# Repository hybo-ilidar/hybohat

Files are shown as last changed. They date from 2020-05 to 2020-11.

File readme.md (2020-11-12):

# Hybohat Development Board 

## Update R3

Correction was made for Arduino Nano module.
ESP32 module was adjusted for use with male pin header modules.

## Introduction

The Hybohat module was designed as a simple, passive way to interconnect
the User I/O connector of the iLidar to a variety of common development
boards.  These are:

* STM32F4 Discovery
* Arduino Uno & Leonardo
* STM32F429ZI Nucleo
* ESP32
* Raspberry Pi & Pi Zero
* Arduino Nano (and STM32F103 Nano form-factor)

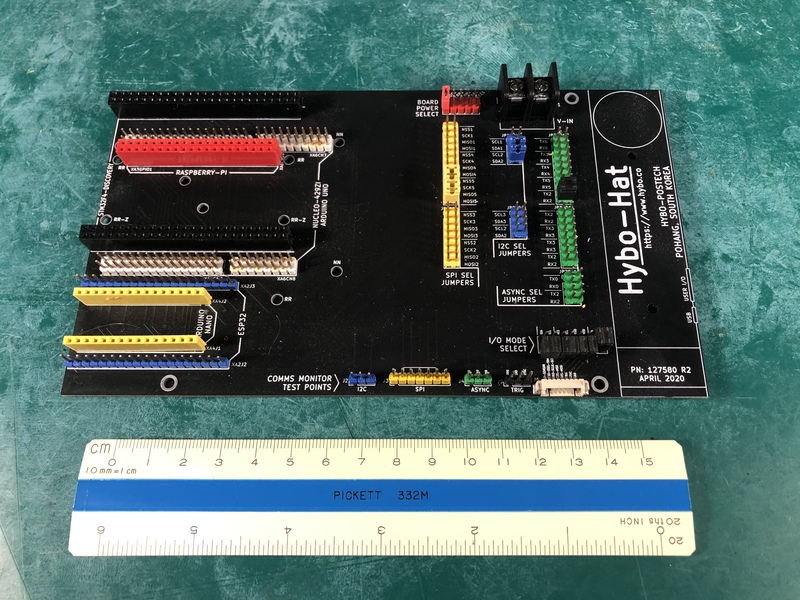
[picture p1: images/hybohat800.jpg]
Hybohat Assembly


## Concept

The board can be envisioned as a large cross-bar switch with each
dev board's I/O ports conected to a bus.  In case a development board
has multiple ports of the same time, the desired port is selected with 
jumpers in the three vertical columns labeled 

* `SPI SEL JUMPERS` (JP4NN1, JP4DD1)
* `I2C SEL JUMPERS` (JP2NN1, JP2DD1)
* `ASYNC SEL JUMPERS` (JP3NN1, JP3DD1, JP2EE1)

One end of this bus is connected to iLidar's User I/O
connector by the jumper block labeled: `I/O MODE SELECT (JP6)`
Note that only one mode can be operational at a time.

The other end of the bus is terminated in four connectors which can be
used to probe and monitor the I/O:

* `I2C` (J2)
* `SPI` (J3)
* `ASYNC` (J4)
* `TRIG` (J5)

## Development Boards

IMPORTANT: ONLY ONE DEVELOPMENT BOARD MAY BE CONNECTED AT ONE TIME

* Module A2, ESP32
  - XA2J2
  - XA2J3

* Module A3, Raspberry Pi & Pi Zero
  - XA3GPIO1

* Module A4, Arduino Nano
  - XA4J1 
  - XA4J2 

* Module A5, STM32F4 Discovery 
  - XA5P1
  - XA5P2

* Module A6, STM32F429ZI Nucleo Arduino Uno & Leonardo
  - XA6CN7
  - XA6CN8
  - XA6CN9
  - XA6CN10

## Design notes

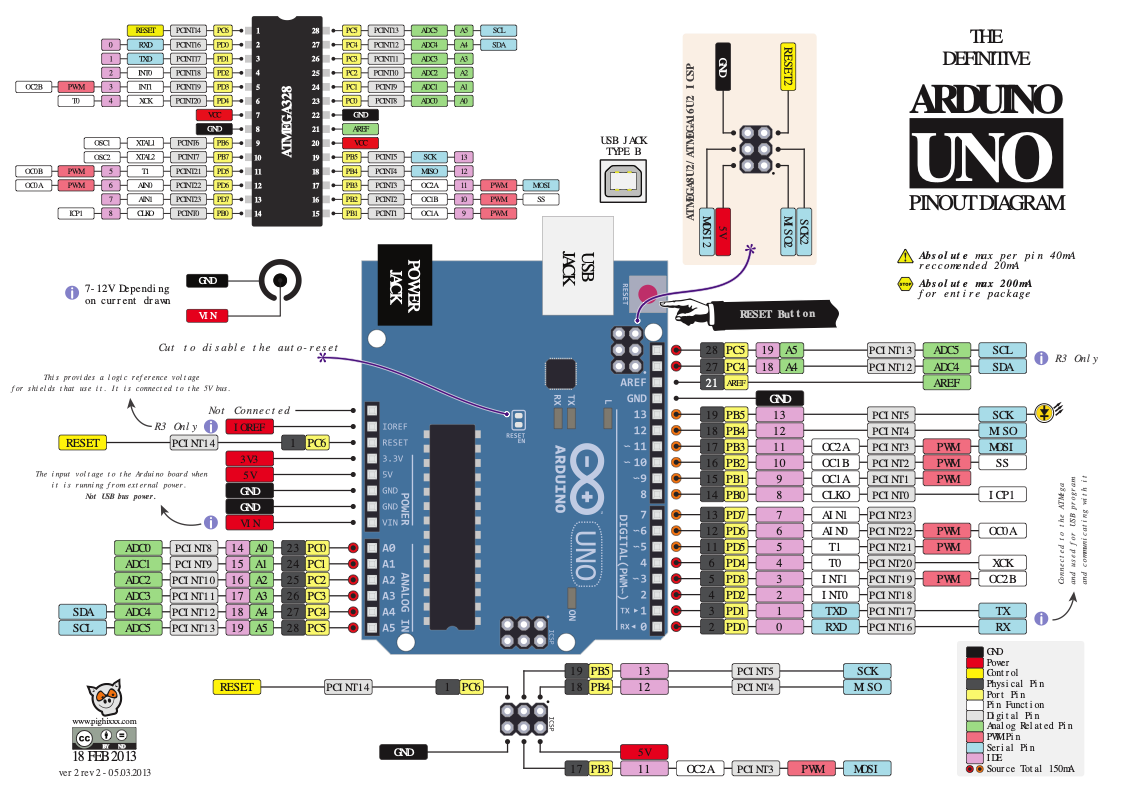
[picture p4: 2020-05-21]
datasheets/modules/pinout-arduino-uno.png

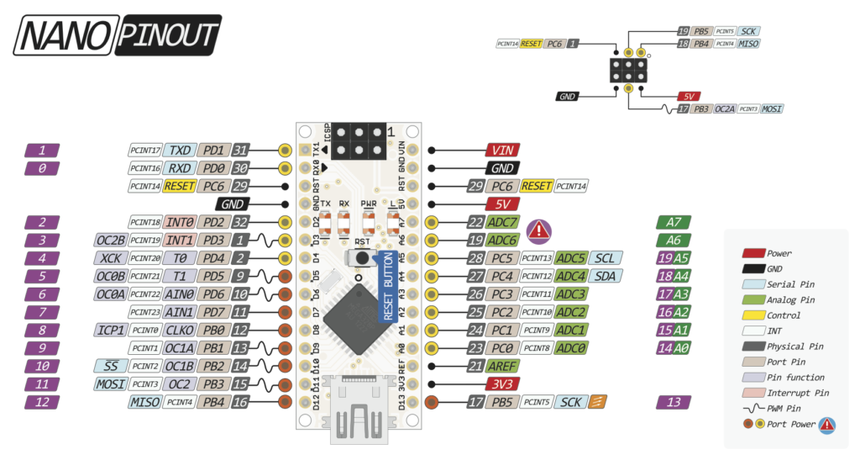
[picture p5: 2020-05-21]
datasheets/modules/pinout-arduino-nano.png

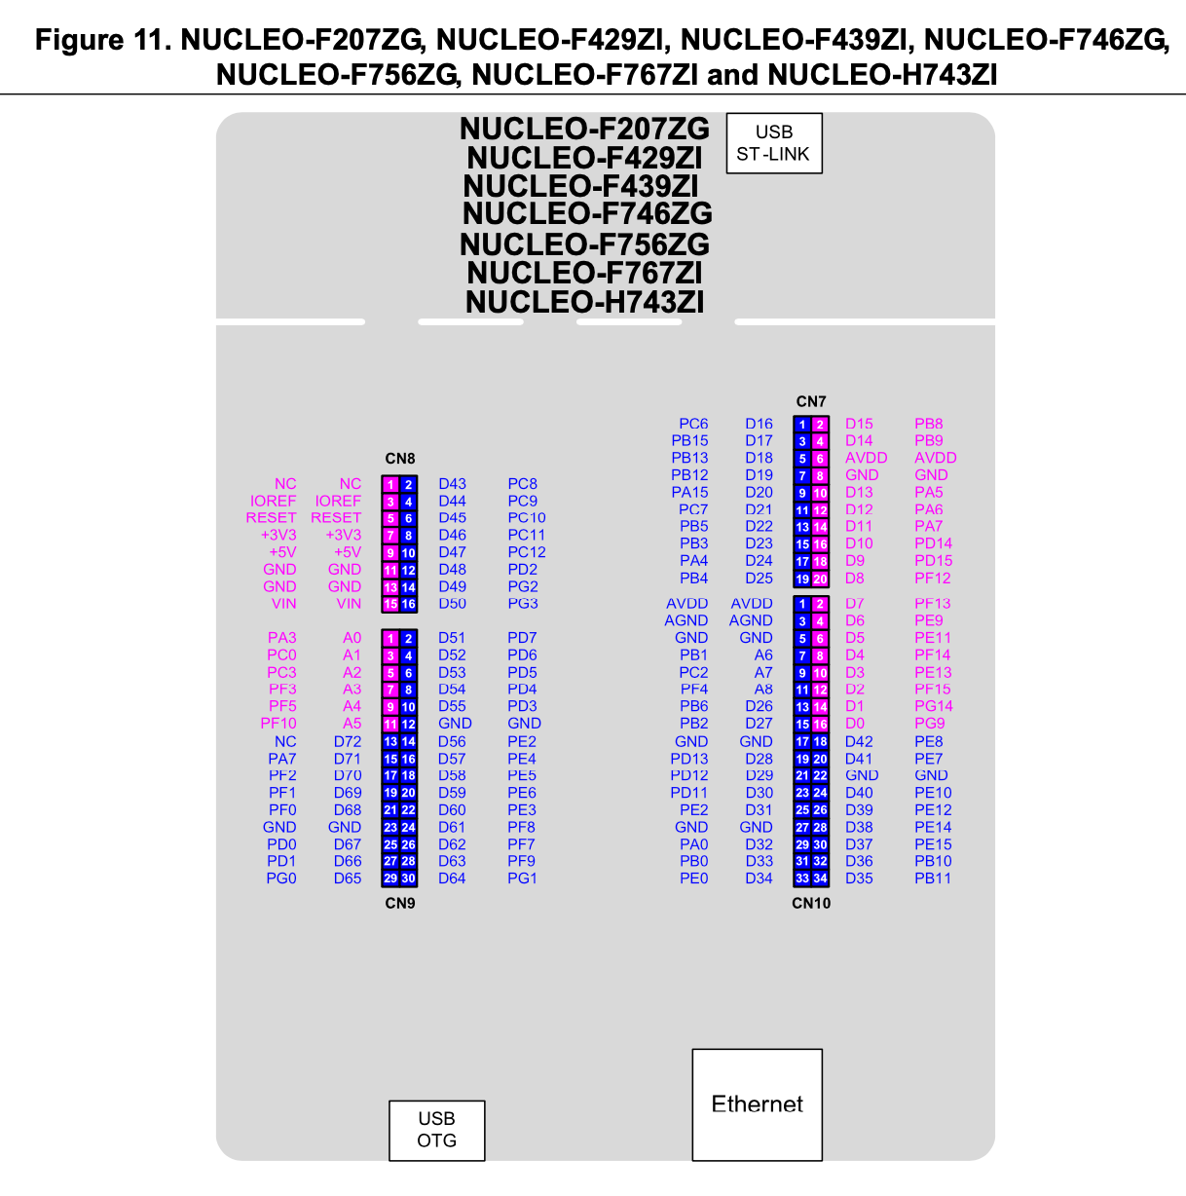
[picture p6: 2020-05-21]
datasheets/modules/pinout-nucleo-429zi.png

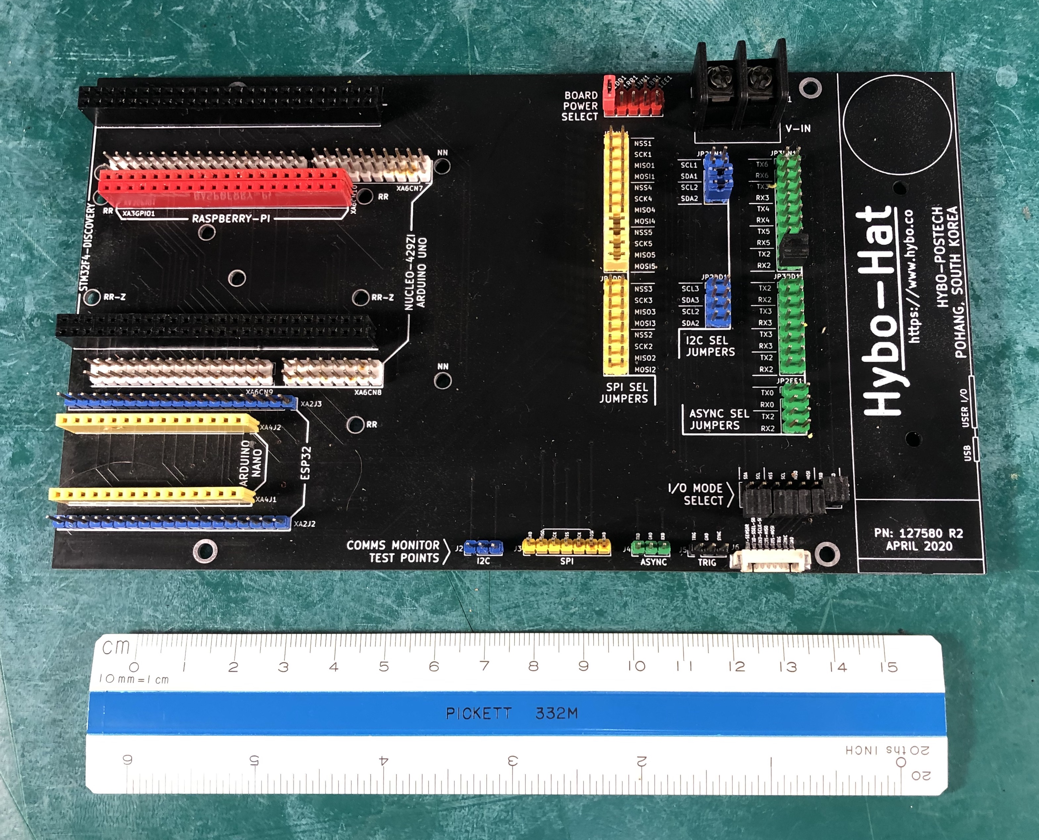
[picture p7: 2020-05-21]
images/hybohat-assy-top.jpg

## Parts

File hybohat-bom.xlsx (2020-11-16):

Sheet: BOM
HYBOHAT ASSEMBLY
P/N 127580
2020-11-11
FN | Ref | ALL Qty | EE Qty | RR Qty | BB Qty | DD Qty | NN Qty | Comm Code | Manufacturer | PartNumber | Value | Cmp name | Module
1 | A1, | 1 | 1 | 1 | 1 | 1 | 1 | ASY | Hybo | 127290 | ASSY_SENSOR_LIDAR | ASSY_SENSOR_LIDAR |  |  |  |  | iLidar Sensor
~~2~~ | ~~A2~~ |  | ~~1~~ |  |  |  |  | ASY |  |  |  |  |  |  |  |  | ESP32
~~3~~ | ~~A3~~ |  |  | ~~1~~ |  |  |  | ASY |  |  |  |  |  |  |  |  | Raspberry Pi & Pi Zero
~~4~~ | ~~A4~~ |  |  |  | ~~1~~ |  |  | ASY |  |  |  |  |  |  |  |  | Arduino Nano (and STM32F103 Nano form-factor)
~~5~~ | ~~A5~~ |  |  |  |  | ~~1~~ |  | ASY |  |  |  |  |  |  |  |  | STM32F4 Discovery
~~6~~ | ~~A6~~ |  |  |  |  |  | ~~1~~ | ASY |  |  |  |  |  |  |  |  | STM32F429ZI Nucleo, Arduino Uno & Leonardo
7 | J1, | 1 | 1 | 1 | 1 | 1 | 1 | CON | Molex | 387007502 | DC-PWR-IN | Screw_Terminal_01x02 |  |  |  |  | Connector, Barrier Strip, #6032, 0.325 in pitch, 2 pos'n
8 | J6, | 1 | 1 | 1 | 1 | 1 | 1 | CON | Molex | 532610871 | CONN_1x8 | CONN_1x8 |  | M1x08 |  |  | Connector, Plug, Wafer Pico-Blade, SMD R/A,1.25 mm pitch, 8-pos'n
~~9~~ | J2 | ~~1~~ | ~~1~~ | ~~1~~ | ~~1~~ | ~~1~~ | ~~1~~ | CON |  |  | IO_JACK_M03 | IO_JACK_M03 | I2C | M1x03 | M1 | 3 | Header, Pin, Vertical, 0.1 in. pitch, 0.12/0.23 in head/tail, 1x3 pos'n
~~10~~ | J4 | ~~1~~ | ~~1~~ | ~~1~~ | ~~1~~ | ~~1~~ | ~~1~~ | CON |  |  | IO_JACK_M03 | IO_JACK_M03 | ASYNC | M1x03 | M1 | 3 | Header, Pin, Vertical, 0.1 in. pitch, 0.12/0.23 in head/tail, 1x3 pos'n
~~11~~ | J5 | ~~1~~ | ~~1~~ | ~~1~~ | ~~1~~ | ~~1~~ | ~~1~~ | CON |  |  | IO_JACK_M03 | IO_JACK_M03 | TRIG | M1x03 | M1 | 3 | Header, Pin, Vertical, 0.1 in. pitch, 0.12/0.23 in head/tail, 1x3 pos'n
~~12~~ | J3, | ~~1~~ | ~~1~~ | ~~1~~ | ~~1~~ | ~~1~~ | ~~1~~ | CON |  |  | IO_JACK_M07 | IO_JACK_M07 | SPI | M1x07 | M1 | 7 | Header, Pin, Vertical, 0.1 in. pitch, 0.12/0.23 in head/tail, 1x7 pos'n
~~13~~ | JP1 | ~~1~~ | 1 | 1 | 1 | 1 | 1 | CON |  |  | PWR-SEL | IO_JACK_M2x01B | POWER | M2x10 | M2 | 10 | Header, Pin, Vertical, 0.1 in. pitch, 0.12/0.23 in head/tail, 2x10 pos'n
~~14~~ | JP6 | ~~1~~ | 1 | 1 | 1 | 1 | 1 | CON |  |  | IO_JACK_M2x08B | IO_JACK_M2x08B_SENSOR | MODE | M2x08 | M2 | 8 | Header, Pin, Vertical, 0.1 in. pitch, 0.12/0.23 in head/tail, 2x8 pos'n
15 | LK1-LK17 | 17 | 17 | 17 | 17 | 17 | 17 | CON | Sullins | QPC02SXGN-RC |  |  | POWER | LKx01 |  |  | Connector, Shorting Jumper, 0.1 in. pitch
20 |  | 1 | 1 | 1 | 1 | 1 | 1 | PCB | Hybo | 127581 |  |  |  |  |  |  | Printed circuit board, Hybohat
~~21~~ | XA2J2, XA2J3 | ~~2~~ | ~~2~~ |  |  |  |  | CON | Sullins | PPPC201LFBN-RC | EE_F1x19_J2 | IO_JACK_F19 | EE | F1x19 | F1 | 38 | Header, Socket, Vertical, 0.1 in. pitch, 0.12/0.23 in head/tail, 1x19 pos'n
~~22~~ | JP2EE1, | ~~1~~ | ~~1~~ |  |  |  |  | CON |  |  | EE_ASYNC_SEL | IO_JACK_M2x04B | EE | M2x04 | M2 | 4 | Header, Pin, Vertical, 0.1 in. pitch, 0.12/0.23 in head/tail, 2x4 pos'n
23 | XA3GPIO1, | 1 |  | 1 |  |  |  | CON | Sullins | PPPC202LFBN-RC | RR_F2x20_GPIO | IO_JACK_F2x20B | RR | F2x20 | F2 | 20 | Header, Socket, Vertical, 0.1 in. pitch, 0.12/0.23 in head/tail, 2x20 pos'n
24 | XA4J1, XA4J2 | 2 |  |  | 2 |  |  | CON | Sullins | PPPC151LFBN-RC | BB_F1x15_J1 | IO_JACK_F15 | BB | F1x15 | F1 | 30 | Header, Socket, Vertical, 0.1 in. pitch, 0.12/0.23 in head/tail, 2x15 pos'n
25 | XA5P1, XA5P2 | 2 |  |  |  | 2 |  | CON | Sullins | PPPC252LFBN-RC | DD_F2x25_P1 | IO_JACK_F2x25 | DD | F2x25 | F2 | 50 | Header, Socket, Vertical, 0.1 in. pitch, 0.12/0.23 in head/tail, 2x25 pos'n
~~26~~ | JP2DD1, | ~~1~~ |  |  |  | ~~1~~ |  | CON |  |  | DD_I2C_SEL | IO_JACK_M2x04B | DD | M2x04 | M2 | 4 | Header, Pin, Vertical, 0.1 in. pitch, 0.12/0.23 in head/tail, 2x4 pos'n
~~27~~ | JP3DD1, | ~~1~~ |  |  |  | ~~1~~ |  | CON |  |  | DD_ASYNC_SEL | IO_JACK_M2x08B | DD | M2x08 | M2 | 8 | Header, Pin, Vertical, 0.1 in. pitch, 0.12/0.23 in head/tail, 2x8 pos'n
~~28~~ | JP4DD1, | ~~1~~ |  |  |  | ~~1~~ |  | CON |  |  | DD_SPI_SEL | IO_JACK_M2x08B | DD | M2x08 | M2 | 8 | Header, Pin, Vertical, 0.1 in. pitch, 0.12/0.23 in head/tail, 2x8 pos'n
~~29~~ | XA6CN7, | ~~1~~ |  |  |  |  | ~~1~~ | CON |  |  | NN_M2x10_CN7 | IO_JACK_M2x10B_NN429ZI | NN | M2x10 | M2 | 10 | Header, Pin, Vertical, 0.1 in. pitch, 0.12/0.23 in head/tail, 2x10 pos'n
~~30~~ | XA6CN8, | ~~1~~ |  |  |  |  | ~~1~~ | CON |  |  | NN_M2x8_CN8 | IO_JACK_M2x08B_NN429ZI | NN | M2x08 | M2 | 8 | Header, Pin, Vertical, 0.1 in. pitch, 0.12/0.23 in head/tail, 2x8 pos'n
~~31~~ | XA6CN9, | ~~1~~ |  |  |  |  | ~~1~~ | CON |  |  | NN_M2x15_CN9 | IO_JACK_M2x15B_NN429ZI | NN | M2x15 | M2 | 15 | Header, Pin, Vertical, 0.1 in. pitch, 0.12/0.23 in head/tail, 2x15 pos'n
~~32~~ | XA6CN10, | ~~1~~ |  |  |  |  | ~~1~~ | CON |  |  | NN_M2x17_CN10 | IO_JACK_M2x17B_NN429ZI | NN | M2x17 | M2 | 17 | Header, Pin, Vertical, 0.1 in. pitch, 0.12/0.23 in head/tail, 2x17 pos'n
~~33~~ | JP2NN1, | ~~1~~ |  |  |  |  | ~~1~~ | CON |  |  | NN_I2C_SEL | IO_JACK_M2x04B | NN | M2x04 | M2 | 4 | Header, Pin, Vertical, 0.1 in. pitch, 0.12/0.23 in head/tail, 2x17 pos'n
~~34~~ | JP3NN1, | ~~1~~ |  |  |  |  | ~~1~~ | CON |  |  | NN_ASYNC_SEL | IO_JACK_M2x10B | NN | M2x10 | M2 | 10 | Header, Pin, Vertical, 0.1 in. pitch, 0.12/0.23 in head/tail, 2x10 pos'n
~~35~~ | JP4NN1, | ~~1~~ |  |  |  |  | ~~1~~ | CON |  |  | NN_SPI_SEL | IO_JACK_M2x12B | NN | M2x12 | M2 | 12 | Header, Pin, Vertical, 0.1 in. pitch, 0.12/0.23 in head/tail, 2x12 pos'n
90 | Various | 0 | 0 | 0 | 0 | 0 | 0 | ASSY |  |  |  |  |  |  |  |  | Development Module(s), Customer Provided
91 | XA2J2, XA2J3 | 2 | 2 | 2 | 2 | 2 | 2 | CON | Sullins | PPPC201LFBN-RC |  |  | EE | F1x19 |  |  | Must cut from 1x20 socket, this is common for ESP32 because a 1x19 is very rare
92 | J2-J5 | 1 | 1 | 1 | 1 | 1 | 1 | CON | Sullins | PRPC040SAAN-RC |  |  | various | various |  |  | Snap required lengths from this single 1x40 Male header
93 | Various | 4 | 4 | 4 | 4 | 4 | 4 | CON | Sullins | PRPC040DAAN-RC |  |  | various | various |  |  | Snap required lengths from these 2x40 Male headers
 |  |  |  |  |  |  |  |  |  |  |  |  |  |  | M1 | 16 | 1x40 qty 1, e.g., Sullins 11635 family, PRPC040SAAN-RC or equivalent
 |  |  |  |  |  |  |  |  |  |  |  |  |  |  | M2 | 118 | 2x40 qty 4, e.g., Sullins 11636 family, PRPC040DAAN-RC or equivalent

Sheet: BOM-KIT-VERSION
HYBOHAT ASSEMBLY
P/N 127580
2020-11-11
 |  |  | 405 | <=== Total
FN | Ref | ALL Qty | Extended Qty | Comm Code | Manufacturer | PartNumber | Value | Cmp name | Module
7 | J1, | 1 | 405 | CON | Molex | 387007502 | DC-PWR-IN | Screw_Terminal_01x02 |  |  |  |  | Connector, Barrier Strip, #6032, 0.325 in pitch, 2 pos'n
8 | J6, | 1 | 405 | CON | Molex | 532610871 | CONN_1x8 | CONN_1x8 |  | M1x08 |  |  | Connector, Plug, Wafer Pico-Blade, SMD R/A,1.25 mm pitch, 8-pos'n
15 | LK1-LK17 | 17 | 6885 | CON | Sullins | QPC02SXGN-RC |  |  | POWER | LKx01 |  |  | Connector, Shorting Jumper, 0.1 in. pitch
23 | XA3GPIO1, | 1 | 405 | CON | Sullins | PPPC202LFBN-RC | RR_F2x20_GPIO | IO_JACK_F2x20B | RR | F2x20 | F2 | 20 | Header, Socket, Vertical, 0.1 in. pitch, 0.12/0.23 in head/tail, 2x20 pos'n
24 | XA4J1, XA4J2 | 2 | 810 | CON | Sullins | PPPC151LFBN-RC | BB_F1x15_J1 | IO_JACK_F15 | BB | F1x15 | F1 | 30 | Header, Socket, Vertical, 0.1 in. pitch, 0.12/0.23 in head/tail, 2x15 pos'n
25 | XA5P1, XA5P2 | 2 | 810 | CON | Sullins | PPPC252LFBN-RC | DD_F2x25_P1 | IO_JACK_F2x25 | DD | F2x25 | F2 | 50 | Header, Socket, Vertical, 0.1 in. pitch, 0.12/0.23 in head/tail, 2x25 pos'n
91 | XA2J2, XA2J3 | 2 | 810 | CON | Sullins | PPPC201LFBN-RC |  |  | EE | F1x19/20 |  |  | Must cut from 1x20 socket, this is common for ESP32 because a 1x19 is very rare
92 | J2-J5 | 1 | 405 | CON | Sullins | PRPC040SAAN-RC |  |  | various | various |  |  | Snap required lengths from this single 1x40 Male header
93 | Various | 4 | 1620 | CON | Sullins | PRPC040DAAN-RC |  |  | various | various |  |  | Snap required lengths from these 2x40 Male headers

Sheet: BOM-COLORS
 | HYBOHAT ASSEMBLY
 | P/N 127580
 | 2020-11-11
 | FN | Ref | ALL Qty | EE Qty | RR Qty | BB Qty | DD Qty | NN Qty | Comm Code | Manufacturer | PartNumber | Value | Cmp name | Module | Opt Color
 | 1 | A1, | 1 | 1 | 1 | 1 | 1 | 1 | ASY | Hybo | 127290 | ASSY_SENSOR_LIDAR | ASSY_SENSOR_LIDAR |  |  |  |  |  |  | iLidar Sensor
 | 2 | A2 |  | 1 |  |  |  |  | ASY |  |  |  |  |  |  |  |  |  |  | ESP32
 | 3 | A3 |  |  | 1 |  |  |  | ASY |  |  |  |  |  |  |  |  |  |  | Raspberry Pi & Pi Zero
 | 4 | A4 |  |  |  | 1 |  |  | ASY |  |  |  |  |  |  |  |  |  |  | Arduino Nano (and STM32F103 Nano form-factor)
 | 5 | A5 |  |  |  |  | 1 |  | ASY |  |  |  |  |  |  |  |  |  |  | STM32F4 Discovery
 | 6 | A6 |  |  |  |  |  | 1 | ASY |  |  |  |  |  |  |  |  |  |  | STM32F429ZI Nucleo, Arduino Uno & Leonardo
 | 7 | J1, | 1 | 1 | 1 | 1 | 1 | 1 | CON | Molex | 387007502 | DC-PWR-IN | Screw_Terminal_01x02 |  |  |  |  |  |  | Connector, Barrier Strip, #6032, 0.325 in pitch, 2 pos'n
 | 8 | J6, | 1 | 1 | 1 | 1 | 1 | 1 | CON | Molex | 532610871 | CONN_1x8 | CONN_1x8 |  |  | M1x08 |  |  |  | Connector, Plug, Wafer Pico-Blade, SMD R/A,1.25 mm pitch, 8-pos'n
 | 9 | J2 | 1 | 1 | 1 | 1 | 1 | 1 | CON |  |  | IO_JACK_M03 | IO_JACK_M03 | I2C | BLUE | M1x03 | BE:M1 | M1 | 3 | Header, Pin, Vertical, 0.1 in. pitch, 0.12/0.23 in head/tail, 1x3 pos'n
 | 10 | J4 | 1 | 1 | 1 | 1 | 1 | 1 | CON |  |  | IO_JACK_M03 | IO_JACK_M03 | ASYNC | GREEN | M1x03 | GN:M1 | M1 | 3 | Header, Pin, Vertical, 0.1 in. pitch, 0.12/0.23 in head/tail, 1x3 pos'n
 | 11 | J5 | 1 | 1 | 1 | 1 | 1 | 1 | CON |  |  | IO_JACK_M03 | IO_JACK_M03 | TRIG | BLACK | M1x03 | BK:M1 | M1 | 3 | Header, Pin, Vertical, 0.1 in. pitch, 0.12/0.23 in head/tail, 1x3 pos'n
 | 12 | J3, | 1 | 1 | 1 | 1 | 1 | 1 | CON |  |  | IO_JACK_M07 | IO_JACK_M07 | SPI | YELLOW | M1x07 | YW:M1 | M1 | 7 | Header, Pin, Vertical, 0.1 in. pitch, 0.12/0.23 in head/tail, 1x7 pos'n
 | 13 | JP1 | 1 | 1 | 1 | 1 | 1 | 1 | CON |  |  | PWR-SEL | IO_JACK_M2x01B | POWER | RED | M2x10 | RD:M2 | M2 | 10 | Header, Pin, Vertical, 0.1 in. pitch, 0.12/0.23 in head/tail, 2x10 pos'n
 | 14 | JP6 | 1 | 1 | 1 | 1 | 1 | 1 | CON |  |  | IO_JACK_M2x08B | IO_JACK_M2x08B_SENSOR | MODE | BLACK | M2x08 | BK:M2 | M2 | 8 | Header, Pin, Vertical, 0.1 in. pitch, 0.12/0.23 in head/tail, 2x8 pos'n
 | 15 | LK1 | 1 | 1 | 1 | 1 | 1 | 1 | CON | Sullins | QPC02SXGN-RC |  |  | POWER | RED | LKx01 |  |  |  | Connector, Shorting Jumper, 0.1 in. pitch
 | 16 | LK2-LK5 | 4 | 4 | 4 | 4 | 4 | 4 | CON | Sullins | QPC02SXGN-RC |  |  | SPI | YELLOW | LKx01 |  |  |  | Connector, Shorting Jumper, 0.1 in. pitch
 | 17 | LK6-LK7 | 2 | 2 | 2 | 2 | 2 | 2 | CON | Sullins | QPC02SXGN-RC |  |  | I2C | BLUE | LKx01 |  |  |  | Connector, Shorting Jumper, 0.1 in. pitch
 | 18 | LK8-LK9 | 2 | 2 | 2 | 2 | 2 | 2 | CON | Sullins | QPC02SXGN-RC |  |  | ASYNC | GREEN | LKx01 |  |  |  | Connector, Shorting Jumper, 0.1 in. pitch
 | 19 | LK10-LK17 | 8 | 8 | 8 | 8 | 8 | 8 | CON | Sullins | QPC02SXGN-RC |  |  | MODE | BLACK | LKx01 |  |  |  | Connector, Shorting Jumper, 0.1 in. pitch
 | 20 |  | 1 | 1 | 1 | 1 | 1 | 1 | PCB | Hybo | 127581 |  |  |  |  |  |  |  |  | Printed circuit board, Hybohat
 | 21 | XA2J2, XA2J3 | 2 | 2 |  |  |  |  | CON | Sullins | PPPC201LFBN-RC | EE_F1x19_J2 | IO_JACK_F19 | EE | BLUE | F1x19 | BE:F1 | F1 | 38 | Header, Socket, Vertical, 0.1 in. pitch, 0.12/0.23 in head/tail, 1x19 pos'n
 | 22 | JP2EE1, | 1 | 1 |  |  |  |  | CON |  |  | EE_ASYNC_SEL | IO_JACK_M2x04B | EE | GREEN | M2x04 | GN:M2 | M2 | 4 | Header, Pin, Vertical, 0.1 in. pitch, 0.12/0.23 in head/tail, 2x4 pos'n
 | 23 | XA3GPIO1, | 1 |  | 1 |  |  |  | CON | Sullins | PPPC202LFBN-RC | RR_F2x20_GPIO | IO_JACK_F2x20B | RR | RED | F2x20 | RD:F2 | F2 | 20 | Header, Socket, Vertical, 0.1 in. pitch, 0.12/0.23 in head/tail, 2x20 pos'n
 | 24 | XA4J1, XA4J2 | 2 |  |  | 2 |  |  | CON | Sullins | PPPC151LFBN-RC | BB_F1x15_J1 | IO_JACK_F15 | BB | YELLOW | F1x15 | YW:F1 | F1 | 30 | Header, Socket, Vertical, 0.1 in. pitch, 0.12/0.23 in head/tail, 2x15 pos'n
 | 25 | XA5P1, XA5P2 | 2 |  |  |  | 2 |  | CON | Sullins | PPPC252LFBN-RC | DD_F2x25_P1 | IO_JACK_F2x25 | DD | BLACK | F2x25 | BK:F2 | F2 | 50 | Header, Socket, Vertical, 0.1 in. pitch, 0.12/0.23 in head/tail, 2x25 pos'n
 | 26 | JP2DD1, | 1 |  |  |  | 1 |  | CON |  |  | DD_I2C_SEL | IO_JACK_M2x04B | DD | BLUE | M2x04 | BE:M2 | M2 | 4 | Header, Pin, Vertical, 0.1 in. pitch, 0.12/0.23 in head/tail, 2x4 pos'n
 | 27 | JP3DD1, | 1 |  |  |  | 1 |  | CON |  |  | DD_ASYNC_SEL | IO_JACK_M2x08B | DD | GREEN | M2x08 | GN:M2 | M2 | 8 | Header, Pin, Vertical, 0.1 in. pitch, 0.12/0.23 in head/tail, 2x8 pos'n
 | 28 | JP4DD1, | 1 |  |  |  | 1 |  | CON |  |  | DD_SPI_SEL | IO_JACK_M2x08B | DD | YELLOW | M2x08 | YW:M2 | M2 | 8 | Header, Pin, Vertical, 0.1 in. pitch, 0.12/0.23 in head/tail, 2x8 pos'n
 | 29 | XA6CN7, | 1 |  |  |  |  | 1 | CON |  |  | NN_M2x10_CN7 | IO_JACK_M2x10B_NN429ZI | NN | WHITE | M2x10 | WE:M2 | M2 | 10 | Header, Pin, Vertical, 0.1 in. pitch, 0.12/0.23 in head/tail, 2x10 pos'n
 | 30 | XA6CN8, | 1 |  |  |  |  | 1 | CON |  |  | NN_M2x8_CN8 | IO_JACK_M2x08B_NN429ZI | NN | WHITE | M2x08 | WE:M2 | M2 | 8 | Header, Pin, Vertical, 0.1 in. pitch, 0.12/0.23 in head/tail, 2x8 pos'n
 | 31 | XA6CN9, | 1 |  |  |  |  | 1 | CON |  |  | NN_M2x15_CN9 | IO_JACK_M2x15B_NN429ZI | NN | WHITE | M2x15 | WE:M2 | M2 | 15 | Header, Pin, Vertical, 0.1 in. pitch, 0.12/0.23 in head/tail, 2x15 pos'n
 | 32 | XA6CN10, | 1 |  |  |  |  | 1 | CON |  |  | NN_M2x17_CN10 | IO_JACK_M2x17B_NN429ZI | NN | WHITE | M2x17 | WE:M2 | M2 | 17 | Header, Pin, Vertical, 0.1 in. pitch, 0.12/0.23 in head/tail, 2x17 pos'n
 | 33 | JP2NN1, | 1 |  |  |  |  | 1 | CON |  |  | NN_I2C_SEL | IO_JACK_M2x04B | NN | BLUE | M2x04 | BE:M2 | M2 | 4 | Header, Pin, Vertical, 0.1 in. pitch, 0.12/0.23 in head/tail, 2x17 pos'n
 | 34 | JP3NN1, | 1 |  |  |  |  | 1 | CON |  |  | NN_ASYNC_SEL | IO_JACK_M2x10B | NN | GREEN | M2x10 | GN:M2 | M2 | 10 | Header, Pin, Vertical, 0.1 in. pitch, 0.12/0.23 in head/tail, 2x10 pos'n
 | 35 | JP4NN1, | 1 |  |  |  |  | 1 | CON |  |  | NN_SPI_SEL | IO_JACK_M2x12B | NN | YELLOW | M2x12 | YW:M2 | M2 | 12 | Header, Pin, Vertical, 0.1 in. pitch, 0.12/0.23 in head/tail, 2x12 pos'n
 |  |  |  |  |  |  |  |  |  |  |  |  |  |  |  |  |  | M1 | 16 | 1x40 qty 1, e.g., Sullins 11635 family, PRPC040SAAN-RC or equivalent
 |  |  |  |  |  |  |  |  |  |  |  |  |  |  |  |  |  | M2 | 118 | 2x40 qty 4, e.g., Sullins 11636 family, PRPC040DAAN-RC or equivalent
Optional Color details below…
 |  |  |  |  |  |  |  |  |  |  |  |  |  |  |  |  | WE:M1 |  | 0
 |  |  |  |  |  |  |  |  |  |  |  |  |  |  |  |  | WE:M2 |  | 50
 |  |  |  |  |  |  |  |  |  |  |  |  |  |  |  |  | WE:F1 |  | 0
 |  |  |  |  |  |  |  |  |  |  |  |  |  |  |  |  | WE:F2 |  | 0
 |  |  |  |  |  |  |  |  |  |  |  |  |  |  |  |  | BE:M1 |  | 3
 |  |  |  |  |  |  |  |  |  |  |  |  |  |  |  |  | BE:M2 |  | 8
 |  |  |  |  |  |  |  |  |  |  |  |  |  |  |  |  | BE:F1 |  | 38
 |  |  |  |  |  |  |  |  |  |  |  |  |  |  |  |  | BE:F2 |  | 0
 |  |  |  |  |  |  |  |  |  |  |  |  |  |  |  |  | BK:M1 |  | 3
 |  |  |  |  |  |  |  |  |  |  |  |  |  |  |  |  | BK:M2 |  | 8
 |  |  |  |  |  |  |  |  |  |  |  |  |  |  |  |  | BK:F1 |  | 0
 |  |  |  |  |  |  |  |  |  |  |  |  |  |  |  |  | BK:F2 |  | 50
 |  |  |  |  |  |  |  |  |  |  |  |  |  |  |  |  | GN:M1 |  | 3
 |  |  |  |  |  |  |  |  |  |  |  |  |  |  |  |  | GN:M2 |  | 22
 |  |  |  |  |  |  |  |  |  |  |  |  |  |  |  |  | GN:F1 |  | 0
 |  |  |  |  |  |  |  |  |  |  |  |  |  |  |  |  | GN:F2 |  | 0
 |  |  |  |  |  |  |  |  |  |  |  |  |  |  |  |  | YW:M1 |  | 7
 |  |  |  |  |  |  |  |  |  |  |  |  |  |  |  |  | YW:M2 |  | 20
 |  |  |  |  |  |  |  |  |  |  |  |  |  |  |  |  | YW:F1 |  | 30
 |  |  |  |  |  |  |  |  |  |  |  |  |  |  |  |  | YW:F2 |  | 0
 |  |  |  |  |  |  |  |  |  |  |  |  |  |  |  |  | RD:M1 |  | 0
 |  |  |  |  |  |  |  |  |  |  |  |  |  |  |  |  | RD:M2 |  | 10
 |  |  |  |  |  |  |  |  |  |  |  |  |  |  |  |  | RD:F1 |  | 0
 |  |  |  |  |  |  |  |  |  |  |  |  |  |  |  |  | RD:F2 |  | 20

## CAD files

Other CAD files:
mech/hybohat.dwg

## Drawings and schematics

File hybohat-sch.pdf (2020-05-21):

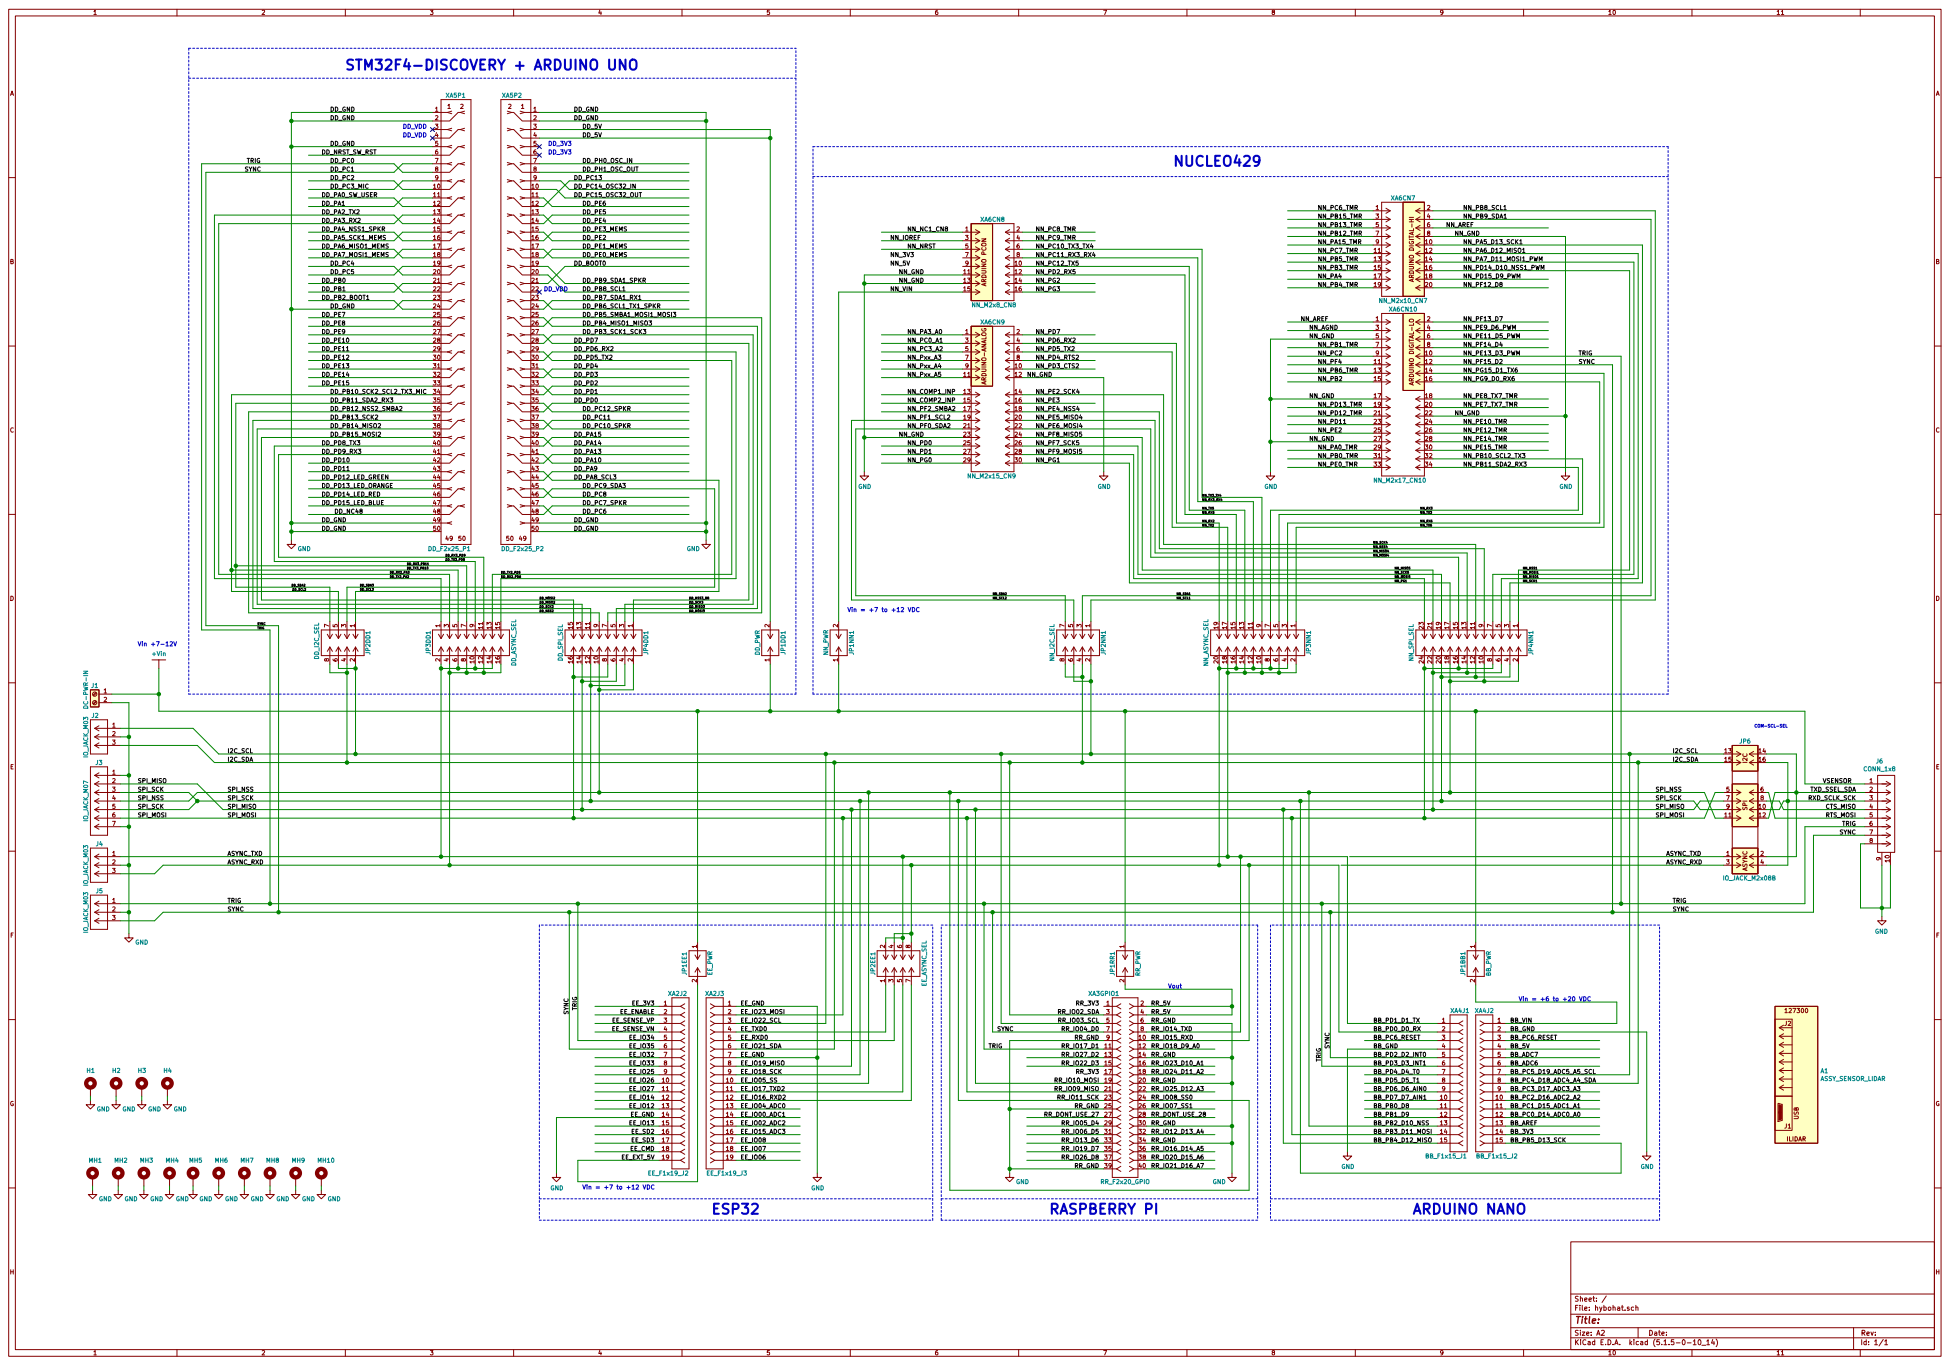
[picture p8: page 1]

NN_PA7_D11_MOSI1_PWM
NN_PD14_D10_NSS1_PWM
NN_PF13_D7 NN_PF12_D8 NN_PD15_D9_PWM | TRIG

NN_PG9_D0_RX6 NN_PG15_D1_TX6 NN_PF15_D2 NN_PE13_D3_PWM | SYNC

NN_PE8_TX7_TMR 20 NN_PE7_TX7_TMR NN_GND

COM-SCL-SEL Vin = +6 to +20 VDC

MH9 GND MH8 GND MH7 GND MH6 GND MH5 GND MH4 GND MH3 GND MH2 GND MH1

File: hybohat.sch Sheet: /

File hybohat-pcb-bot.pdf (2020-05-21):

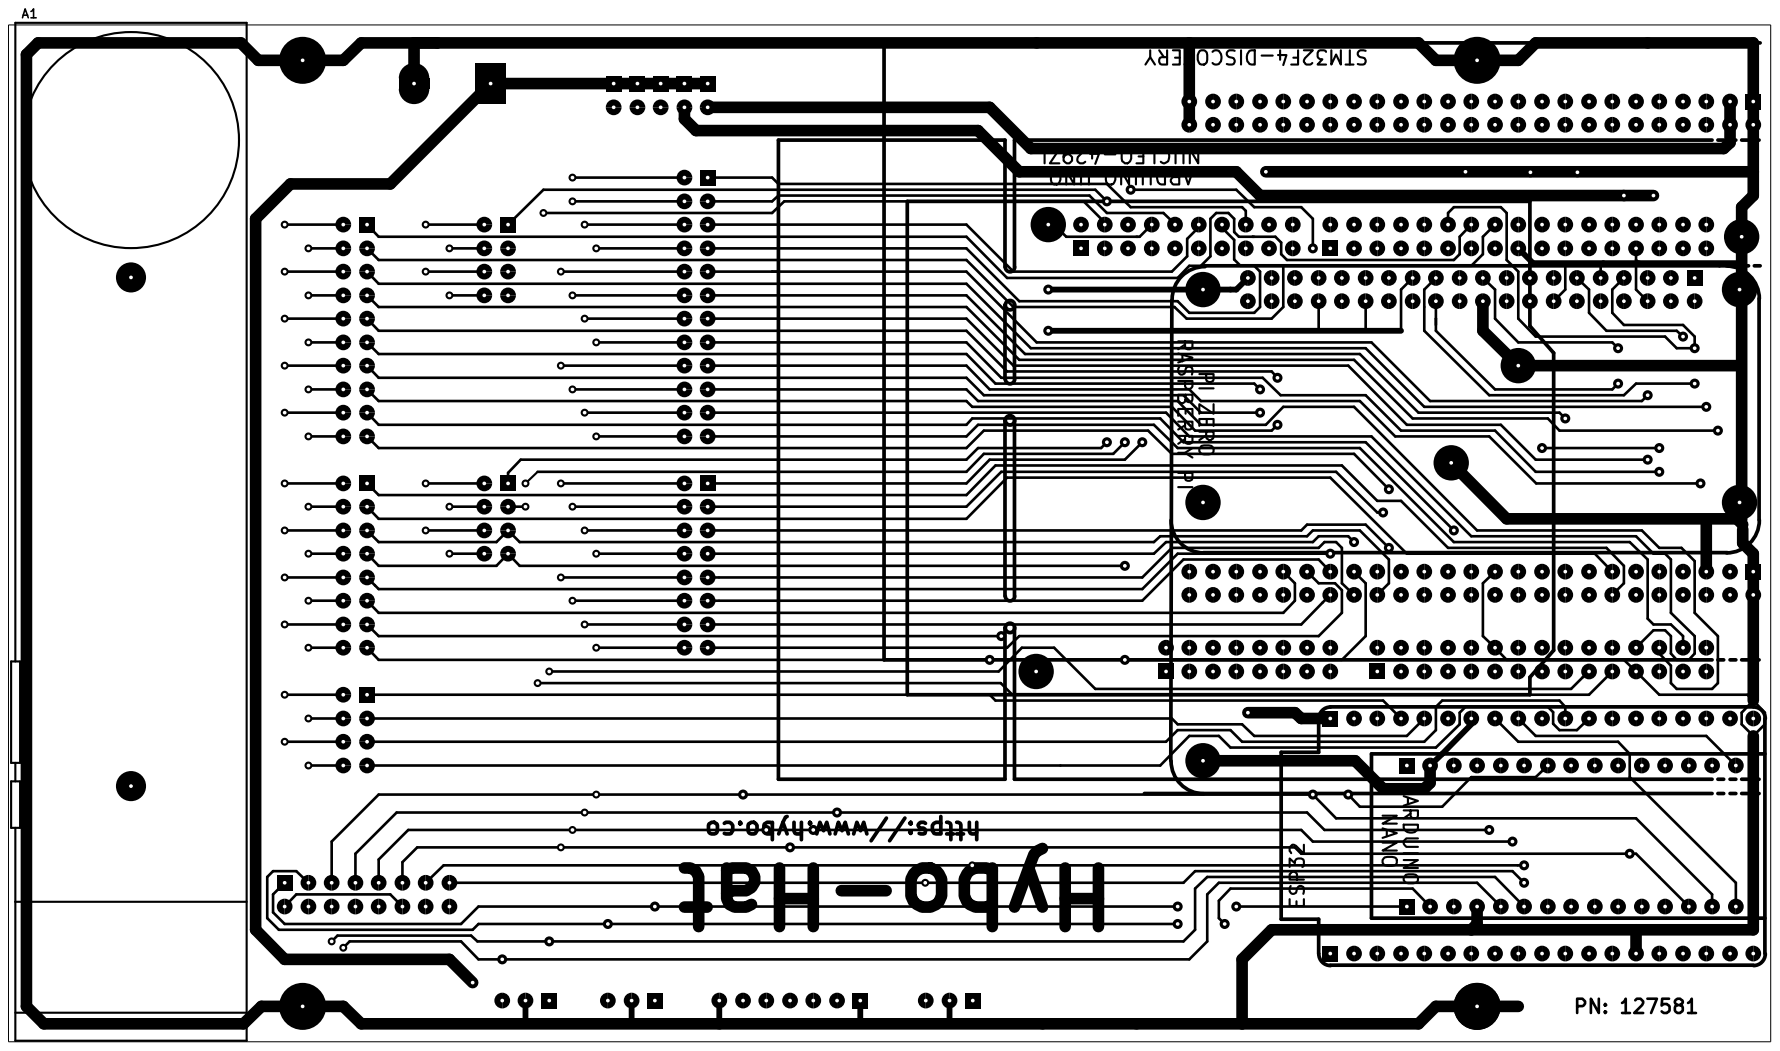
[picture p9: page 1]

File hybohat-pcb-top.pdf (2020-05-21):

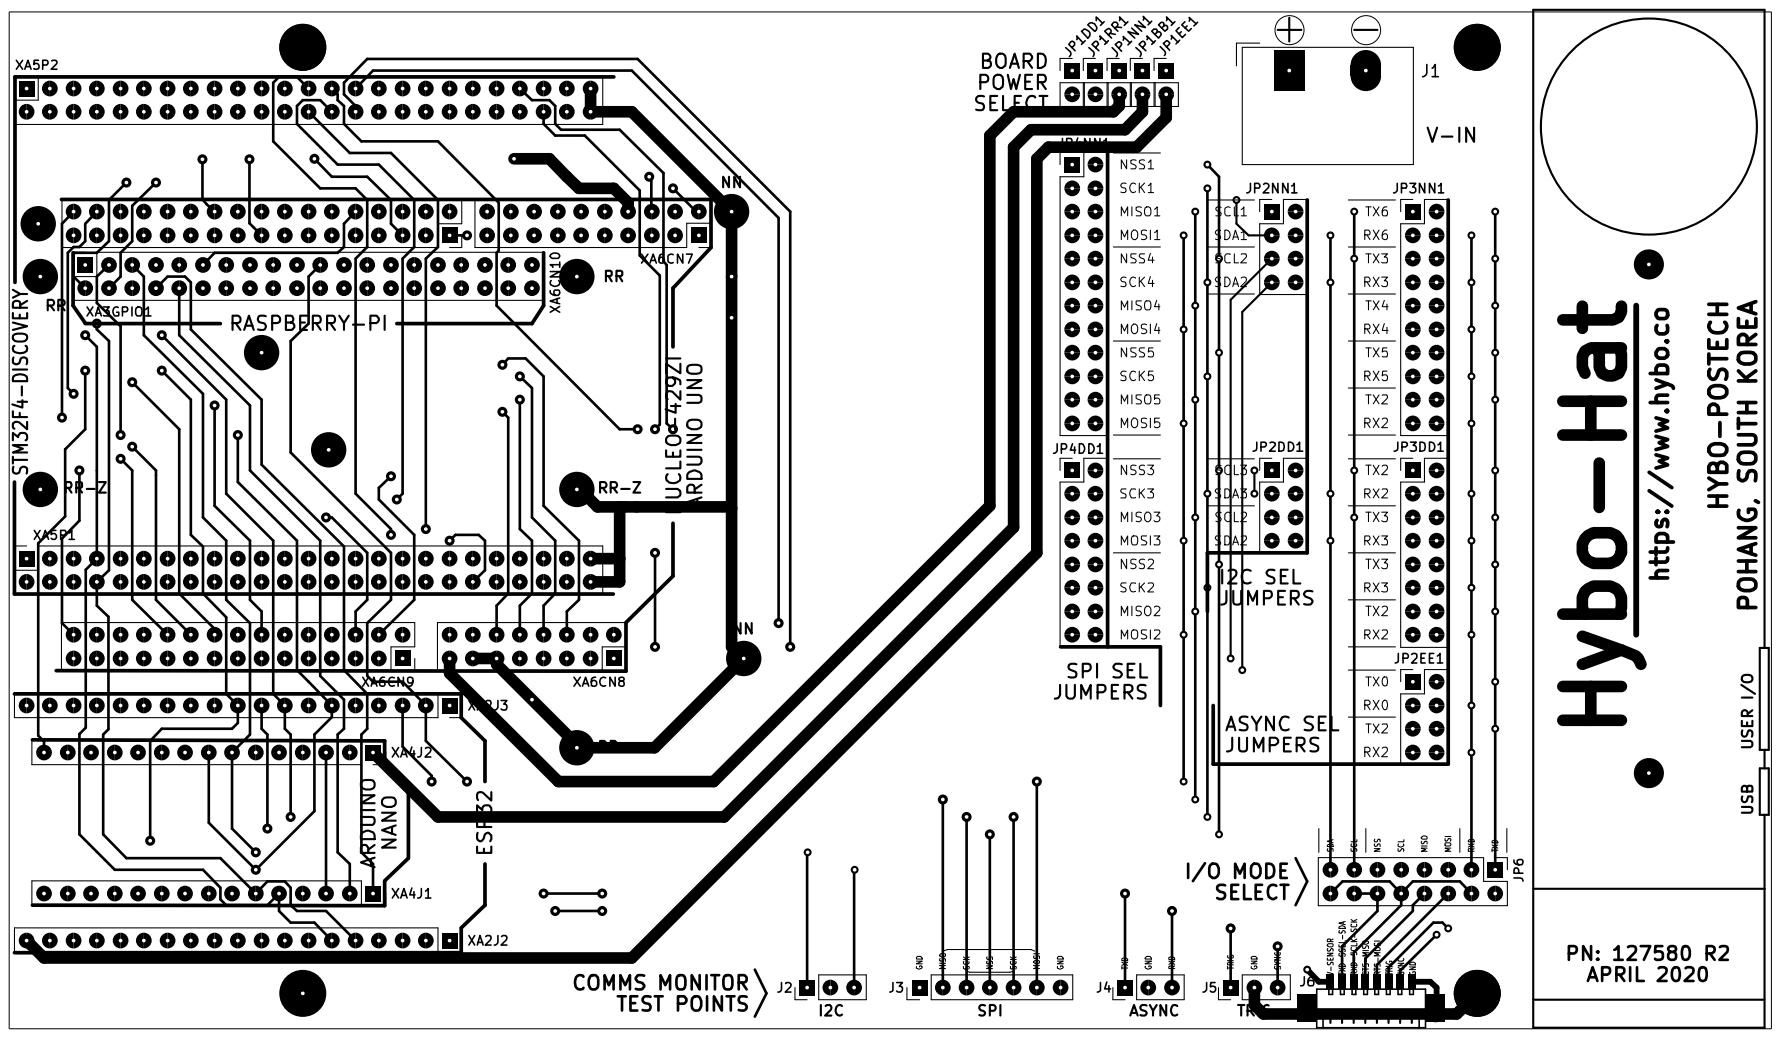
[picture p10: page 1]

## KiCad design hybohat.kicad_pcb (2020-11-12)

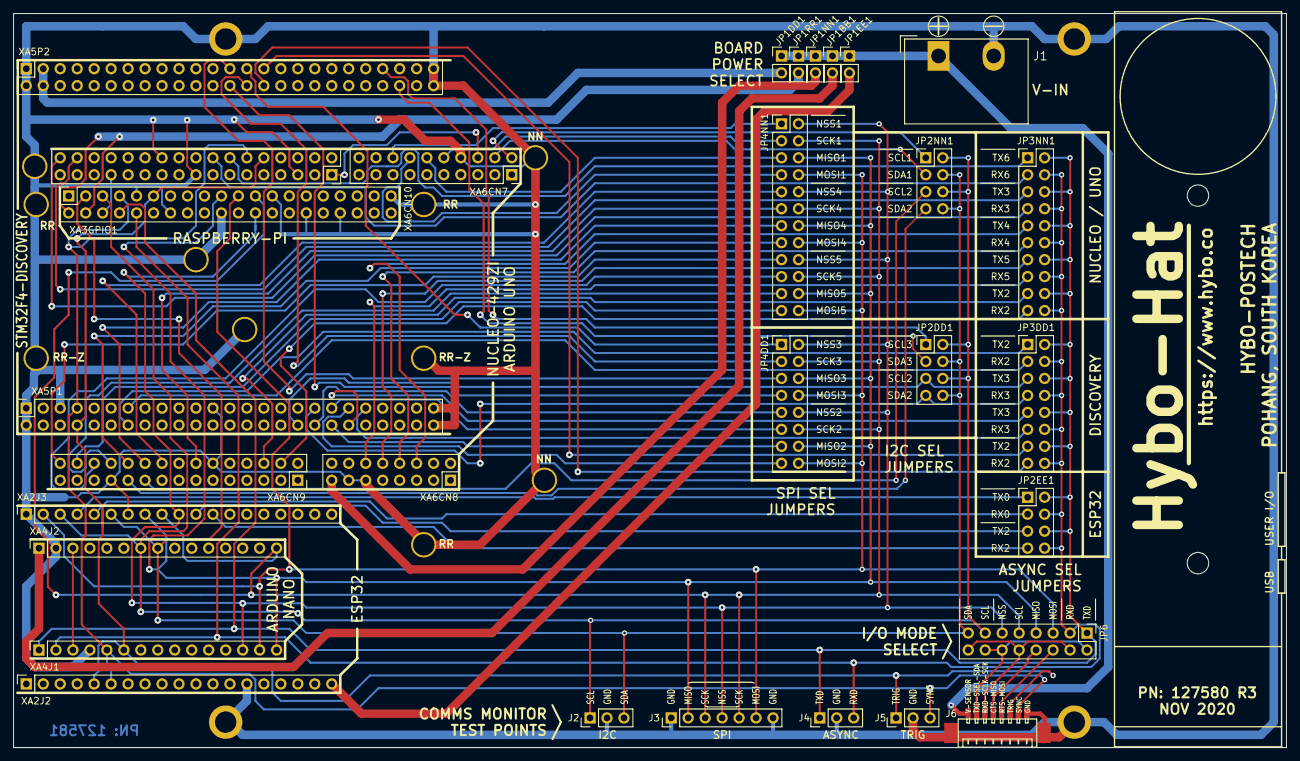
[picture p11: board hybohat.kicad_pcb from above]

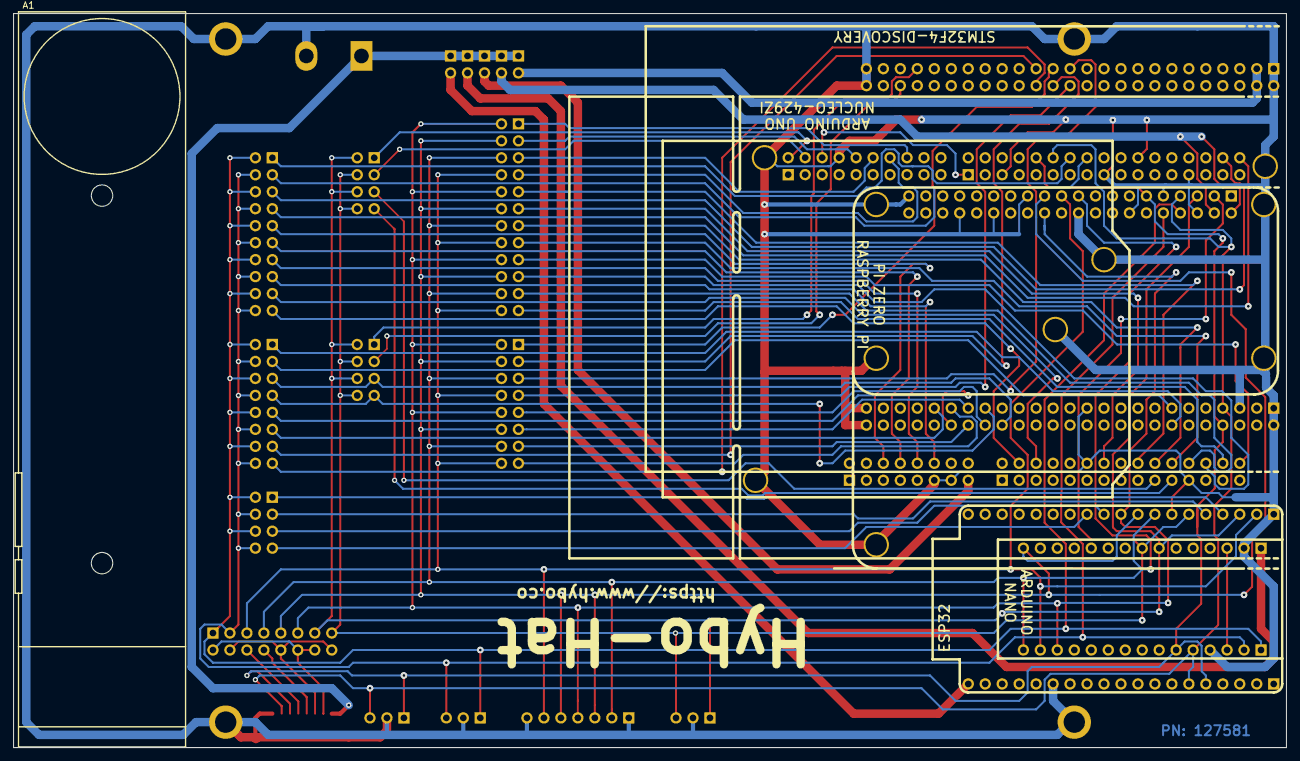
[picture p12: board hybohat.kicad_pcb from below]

Board: 2 copper layers, 190.5 x 109.9 mm, 45 parts (2 on the bottom side), 71 nets.

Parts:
A1: ASSY_SENSOR_LIDAR; iLidar
H1, H2, H3, H4: MountingHole_Pad; MountingHole_3.2mm_M3_Pad
J1: DC-PWR-IN; TerminalBlock_Molex_1x02_0.375
J2, J4, J5: IO_JACK_M03; Connector_PinHeader_2.54mm_PinHeader_1x03_P2.54mm_Vertical
J3: IO_JACK_M07; Connector_PinHeader_2.54mm_PinHeader_1x07_P2.54mm_Vertical
J6: CONN_1x8; USER_IO_CONN
JP1BB1: BB_PWR; Connector_PinHeader_2.54mm_PinHeader_1x02_P2.54mm_Vertical
JP1DD1: DD_PWR; Connector_PinHeader_2.54mm_PinHeader_1x02_P2.54mm_Vertical
JP1EE1: EE_PWR; Connector_PinHeader_2.54mm_PinHeader_1x02_P2.54mm_Vertical
JP1NN1: NN_PWR; Connector_PinHeader_2.54mm_PinHeader_1x02_P2.54mm_Vertical
JP1RR1: RR_PWR; Connector_PinHeader_2.54mm_PinHeader_1x02_P2.54mm_Vertical
JP2DD1: DD_I2C_SEL; Connector_PinHeader_2.54mm_PinHeader_2x04_P2.54mm_Vertical
JP2EE1: EE_ASYNC_SEL; Connector_PinHeader_2.54mm_PinHeader_2x04_P2.54mm_Vertical
JP2NN1: NN_I2C_SEL; Connector_PinHeader_2.54mm_PinHeader_2x04_P2.54mm_Vertical
JP3DD1: DD_ASYNC_SEL; Connector_PinHeader_2.54mm_PinHeader_2x08_P2.54mm_Vertical
JP3NN1: NN_ASYNC_SEL; Connector_PinHeader_2.54mm_PinHeader_2x10_P2.54mm_Vertical
JP4DD1: DD_SPI_SEL; Connector_PinHeader_2.54mm_PinHeader_2x08_P2.54mm_Vertical
JP4NN1: NN_SPI_SEL; Connector_PinHeader_2.54mm_PinHeader_2x12_P2.54mm_Vertical
JP6: IO_JACK_M2x08B; Connector_PinHeader_2.54mm_PinHeader_2x08_P2.54mm_Vertical
MH1, MH2, MH3, MH4, MH5, MH6, MH7, MH8, MH9, MH10: MountingHole_Pad; MountingHole_3.2mm_M3
XA2J2: EE_F1x19_J2; Connector_PinSocket_2.54mm_PinSocket_1x19_P2.54mm_Vertical
XA2J3: EE_F1x19_J3; Connector_PinSocket_2.54mm_PinSocket_1x19_P2.54mm_Vertical
XA3GPIO1: RR_F2x20_GPIO; Connector_PinSocket_2.54mm_PinSocket_2x20_P2.54mm_Vertical
XA4J1: BB_F1x15_J1; Connector_PinSocket_2.54mm_PinSocket_1x15_P2.54mm_Vertical
XA4J2: BB_F1x15_J2; Connector_PinSocket_2.54mm_PinSocket_1x15_P2.54mm_Vertical
XA5P1: DD_F2x25_P1; Connector_PinSocket_2.54mm_PinSocket_2x25_P2.54mm_Vertical
XA5P2: DD_F2x25_P2; Connector_PinSocket_2.54mm_PinSocket_2x25_P2.54mm_Vertical
XA6CN7: NN_M2x10_CN7; PinHeader_2x10_P2.54mm_Vertical_Mirrored
XA6CN8: NN_M2x8_CN8; PinHeader_2x08_P2.54mm_Vertical_Mirrored
XA6CN9: NN_M2x15_CN9; PinHeader_2x15_P2.54mm_Vertical_Mirrored
XA6CN10: NN_M2x17_CN10; PinHeader_2x17_P2.54mm_Vertical_Mirrored

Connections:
+Vin: J1.1, J6.1, JP1BB1.1, JP1DD1.1, JP1EE1.1, JP1NN1.1, JP1RR1.1
/ASYNC_RXD: J4.3, JP2EE1.4, JP2EE1.8, JP3DD1.4, JP3DD1.8, JP3DD1.12, JP3DD1.16, JP3NN1.4, JP3NN1.8, JP3NN1.12, JP3NN1.16, JP3NN1.20, JP6.3, XA3GPIO1.10, XA4J1.2
/ASYNC_TXD: J4.1, JP2EE1.2, JP2EE1.6, JP3DD1.2, JP3DD1.6, JP3DD1.10, JP3DD1.14, JP3NN1.2, JP3NN1.6, JP3NN1.10, JP3NN1.14, JP3NN1.18, JP6.1, XA3GPIO1.8, XA4J1.1
/BB_PB2_D10_NSS: J3.4, JP4DD1.2, JP4DD1.10, JP4NN1.2, JP4NN1.10, JP4NN1.18, JP6.11, XA2J3.10, XA3GPIO1.24, XA4J1.13
/BB_PB3_D11_MOSI: J3.6, JP4DD1.8, JP4DD1.16, JP4NN1.8, JP4NN1.16, JP4NN1.24, JP6.5, XA2J3.2, XA3GPIO1.21, XA4J1.14
/BB_PB4_D12_MISO: J3.2, JP4DD1.6, JP4DD1.14, JP4NN1.6, JP4NN1.14, JP4NN1.22, JP6.7, XA2J3.8, XA3GPIO1.19, XA4J1.15
/BB_PB5_D13_SCK: J3.3, J3.5, JP4DD1.4, JP4DD1.12, JP4NN1.4, JP4NN1.12, JP4NN1.20, JP6.9, XA2J3.9, XA3GPIO1.23, XA4J2.15
/BB_PC4_D18_ADC4_A4_SDA: J2.3, JP2DD1.4, JP2DD1.8, JP2NN1.4, JP2NN1.8, JP6.15, XA2J3.6, XA3GPIO1.3, XA4J2.8
/BB_PC5_D19_ADC5_A5_SCL: J2.1, JP2DD1.2, JP2DD1.6, JP2NN1.2, JP2NN1.6, JP6.13, XA2J3.3, XA3GPIO1.5, XA4J2.7
/BB_PC6_RESET: XA4J1.3, XA4J2.3
/BB_PD2_D2_INT0: J5.3, J6.7, XA2J2.6, XA3GPIO1.7, XA4J1.5, XA5P1.7, XA6CN10.12
/BB_PD3_D3_INT1: J5.1, J6.6, XA2J2.5, XA3GPIO1.11, XA4J1.6, XA5P1.8, XA6CN10.10
/BB_VIN: JP1BB1.2, XA4J2.1
/CTS_MISO: J6.4, JP6.8
/DD_5V: JP1DD1.2, XA5P2.3, XA5P2.4
/DD_MISO2: JP4DD1.13, XA5P1.38
/DD_MISO3: JP4DD1.5, XA5P2.25
/DD_MOSI2: JP4DD1.15, XA5P1.39
/DD_MOSI3: JP4DD1.7, XA5P2.26
/DD_NSS2: JP4DD1.9, XA5P1.36
/DD_NSS3_BB: JP4DD1.1, XA5P2.27
/DD_PA2_TX2: JP3DD1.1, XA5P1.14
/DD_PA3_RX2: JP3DD1.3, XA5P1.13
/DD_PA8_SCL3: JP2DD1.1, XA5P2.43
/DD_PB3_SCK1_SCK3: JP4DD1.3, XA5P2.28
/DD_PB10_SCK2_SCL2_TX3_MIC: JP2DD1.5, JP3DD1.5, XA5P1.34
/DD_PB11_SDA2_RX3: JP2DD1.7, JP3DD1.7, XA5P1.35
/DD_PB13_SCK2: JP4DD1.11, XA5P1.37
/DD_PC9_SDA3: JP2DD1.3, XA5P2.46
/DD_PD5_TX2: JP3DD1.13, XA5P2.29
/DD_PD6_RX2: JP3DD1.15, XA5P2.30
/DD_PD8_TX3: JP3DD1.9, XA5P1.40
/DD_PD9_RX3: JP3DD1.11, XA5P1.41
/EE_EXT_5V: JP1EE1.2, XA2J2.19
/EE_IO16_RXD2: JP2EE1.7, XA2J3.12
/EE_IO17_TXD2: JP2EE1.5, XA2J3.11
/EE_RXD0: JP2EE1.3, XA2J3.5
/EE_TXD0: JP2EE1.1, XA2J3.4
/NN_AREF: XA6CN7.6, XA6CN10.1
/NN_MISO1: JP4NN1.5, XA6CN7.12
/NN_MISO4: JP4NN1.13, XA6CN9.20
/NN_MISO5: JP4NN1.21, XA6CN9.24
/NN_MOSI1: JP4NN1.7, XA6CN7.14
/NN_MOSI4: JP4NN1.15, XA6CN9.22
/NN_MOSI5: JP4NN1.23, XA6CN9.28
/NN_NSS1: JP4NN1.1, XA6CN7.16
/NN_NSS4: JP4NN1.9, XA6CN9.18
/NN_PA5_D13_SCK1: JP4NN1.3, XA6CN7.10
/NN_PB8_SCL1: JP2NN1.1, XA6CN7.2
/NN_PB9_SDA1: JP2NN1.3, XA6CN7.4
/NN_PB10_SCL2_TX3: JP3NN1.5, XA6CN10.32
/NN_PB11_SDA2_RX3: JP3NN1.7, XA6CN10.34
/NN_PC10_TX3_TX4: JP3NN1.9, XA6CN8.6
/NN_PC11_RX3_RX4: JP3NN1.11, XA6CN8.8
/NN_PC12_TX5: JP3NN1.13, XA6CN8.10
/NN_PD2_RX5: JP3NN1.15, XA6CN8.12
/NN_PD5_TX2: JP3NN1.17, XA6CN9.6
/NN_PD6_RX2: JP3NN1.19, XA6CN9.4
/NN_PE2_SCK4: JP4NN1.11, XA6CN9.14
/NN_PF0_SDA2: JP2NN1.7, XA6CN9.21
/NN_PF1_SCL2: JP2NN1.5, XA6CN9.19
/NN_PF7_SCK5: JP4NN1.19, XA6CN9.26
/NN_PG1: JP4NN1.17, XA6CN9.30
/NN_PG9_D0_RX6: JP3NN1.3, XA6CN10.16
/NN_PG15_D1_TX6: JP3NN1.1, XA6CN10.14
/NN_VIN: JP1NN1.2, XA6CN8.15
/RR_5V: JP1RR1.2, XA3GPIO1.2, XA3GPIO1.4
/RTS_MOSI: J6.5, JP6.6
/RXD_SCLK_SCK: J6.3, JP6.4, JP6.10, JP6.16
/TXD_SSEL_SDA: J6.2, JP6.2, JP6.12, JP6.14
GND: H1.1, H2.1, H3.1, H4.1, J1.2, J2.2, J3.1, J3.7, J4.2, J5.2, J6.8, J6.9, J6.10, MH1.1, MH2.1, MH3.1, MH4.1, MH5.1, MH6.1, MH7.1, MH8.1, MH9.1, MH10.1, XA2J2.14, XA2J3.1, XA2J3.7, XA3GPIO1.6, XA3GPIO1.9, XA3GPIO1.14, XA3GPIO1.20, XA3GPIO1.25, XA3GPIO1.30, XA3GPIO1.34, XA3GPIO1.39, XA4J1.4, XA4J2.2, XA5P1.1, XA5P1.2, XA5P1.5, XA5P1.23, XA5P1.49, XA5P1.50, XA5P2.1, XA5P2.2, XA5P2.49, XA5P2.50, XA6CN7.8, XA6CN8.11, XA6CN8.13, XA6CN9.12, XA6CN9.23, XA6CN10.5, XA6CN10.17, XA6CN10.22, XA6CN10.27

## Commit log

2020-05-21 Initial public release
    [bom.xlsx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]
2020-11-12 updates for rev3, fixed Arduino Nano
    [bom.xlsx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]
2020-11-12 changed ESP32 module to have male pins
    [hybohat-B_Cu.gbr, hybohat-B_Mask.gbr, hybohat-B_Paste.gbr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]
2020-11-12 Updated BOM with to-buy details
    [hybohat-bom.xlsx]
2020-11-16 added kit quantities to BOM
    [hybohat-bom.xlsx]
